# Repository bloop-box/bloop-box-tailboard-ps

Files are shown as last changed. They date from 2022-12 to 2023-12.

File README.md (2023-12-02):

# Bloop Box Tailboard with Power Supply

## THIS IS NO LONGER MAINTAINED AND THEREFORE ARCHIVED! 



Tailboard 3D Render

[Documentation](https://bloop-box.github.io/bloop-box-tailboard)

The board is designed using KiCAD 6 with production and assembly by JLCPCB in mind. All parts are selected to be
available from JLCPCB. At the time of writing as many parts as possible are used from their basic library.

- two power inputs
  - 5.5x2.1mm barrel-jack
  - USB-C
- Can handle 5V to 28V inputs
- Can deliver 5V with up to 3A to the mainboard (assuming it gets enough power)
- Additional circuitry to prevent damage in case two power supplies are connected
- Two buttons connected to the Raspberry Pi, per default used for volume control
- Three LEDs 
  - One to show status of power supply
  - Two can be remote-controlled by Raspberry Pi through the Mainboard

If you just need the 5V USB-C input and don't want the active circuitry you can use the [Tailboard Light](https://github.com/bloop-box/bloop-box-tailboard-light).

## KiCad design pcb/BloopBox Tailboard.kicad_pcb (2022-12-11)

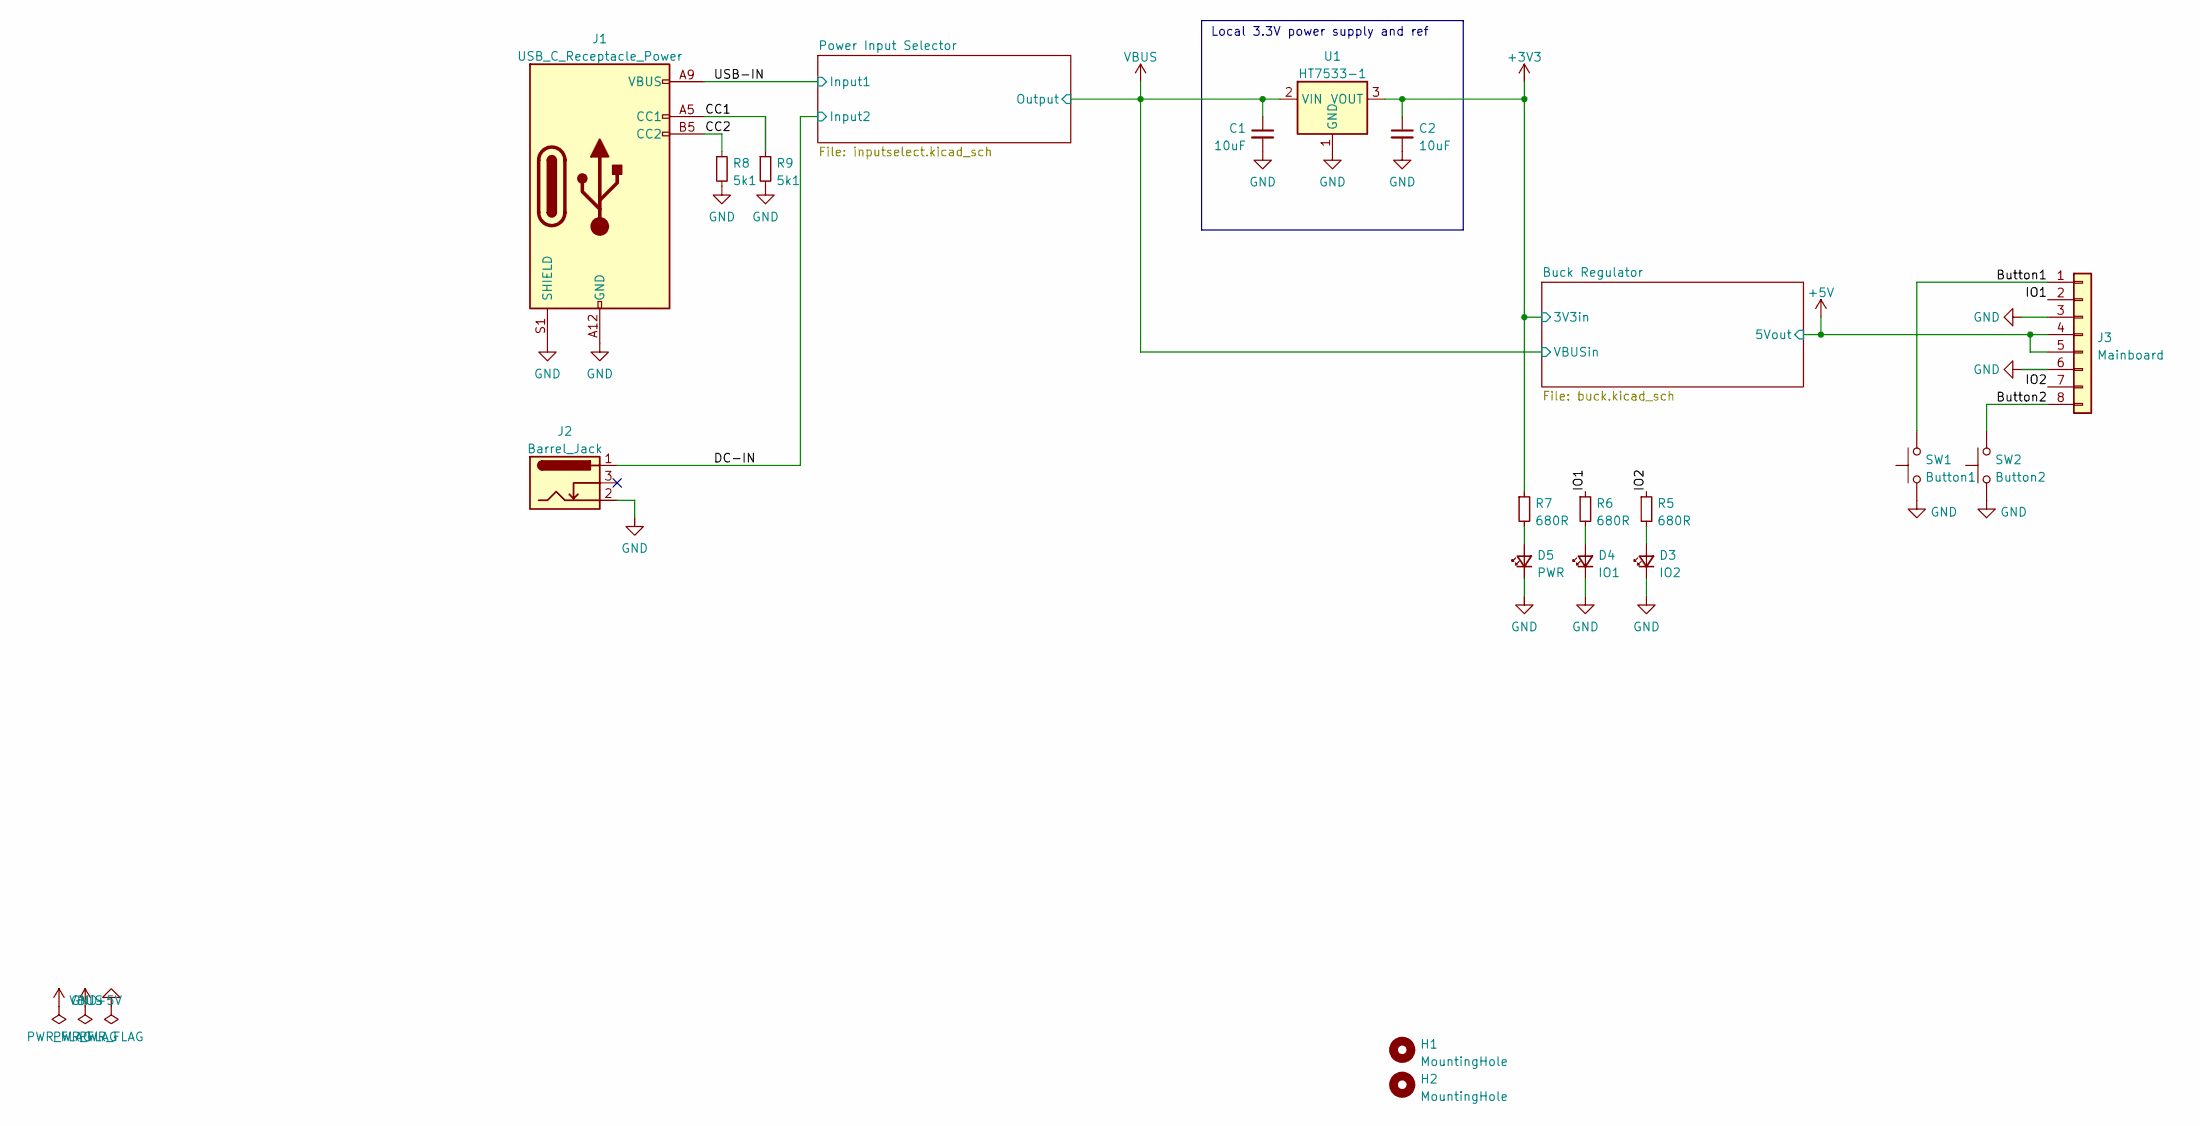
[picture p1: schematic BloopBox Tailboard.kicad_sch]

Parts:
C1: 10uF; C_0805_2012Metric; LCSC C440198
C2: 10uF; C_0402_1005Metric; LCSC C15525
D3: IO2; LED_0603_1608Metric; LCSC C72038
D4: IO1; LED_0603_1608Metric; LCSC C72038
D5: PWR; LED_0603_1608Metric; LCSC C72038
H1, H2: MountingHole; MountingHole_3.2mm_M3_Pad
J1: USB_C_Receptacle_Power; GCT_USB4125-GF-A_REVA2; LCSC C283540
J2: Barrel_Jack; BarrelJack_Horizontal
J3: Mainboard; JST_PH_S8B-PH-K_1x08_P2.00mm_Horizontal; LCSC C14531
R5, R6, R7: 680R; R_0402_1005Metric; LCSC C25130
R8, R9: 5k1; R_0402_1005Metric; LCSC C25905
SW1: Button1; SW_Tactile_SPST_Angled_PTS645Vx83-2LFS; LCSC C338650
SW2: Button2; SW_Tactile_SPST_Angled_PTS645Vx83-2LFS; LCSC C338650
U1: HT7533-1; SOT-89-3; LCSC C14289

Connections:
+3V3: C2.1, R7.1, U1.3 (VOUT); also elsewhere on the board
+5V: J3.4, J3.5; also elsewhere on the board
/Button1: J3.1, SW1.2
/Button2: J3.8, SW2.2
/CC1: J1.A5 (CC1), R9.1
/CC2: J1.B5 (CC2), R8.1
/DC-IN: J2.1; also elsewhere on the board
/IO1: J3.2, R6.1
/IO2: J3.7, R5.1
/USB-IN: J1.A9 (VBUS), J1.B9 (VBUS); also elsewhere on the board
GND: C1.2, C2.2, D3.1 (K), D4.1 (K), D5.1 (K), J1.A12 (GND), J1.B12 (GND), J1.S1 (SHIELD), J2.2, J3.3, J3.6, R8.2, R9.2, SW1.1, SW2.1, U1.1 (GND); also elsewhere on the board
unnamed: D3.2 (A), R5.2
unnamed: D4.2 (A), R6.2
unnamed: D5.2 (A), R7.2
VBUS: C1.1, U1.2 (VIN); also elsewhere on the board

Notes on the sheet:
Local 3.3V power supply and ref

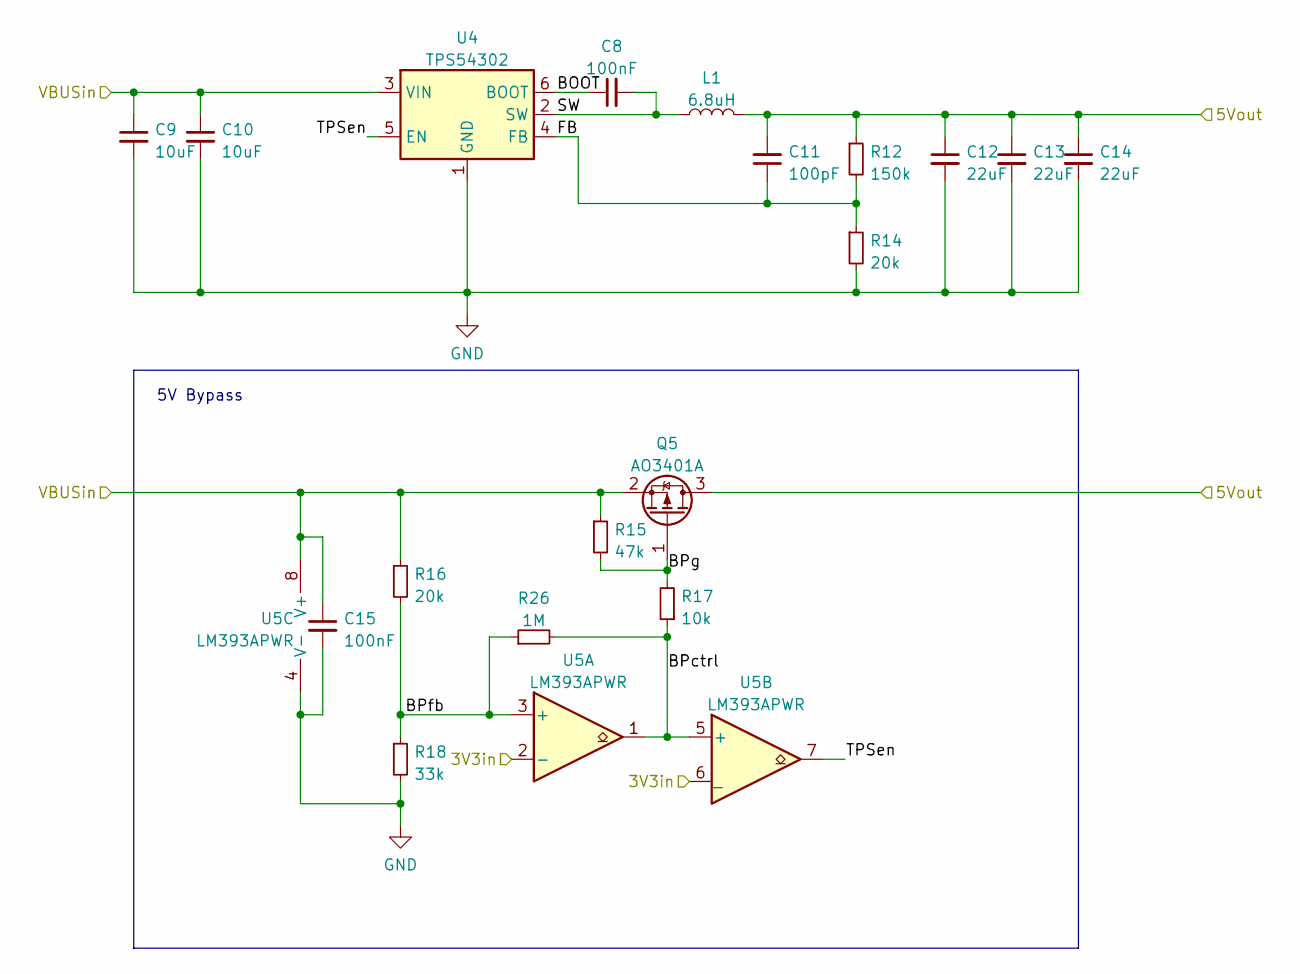
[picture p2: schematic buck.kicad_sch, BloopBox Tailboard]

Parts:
C8: 100nF; C_0402_1005Metric; LCSC C1525
C9, C10: 10uF; C_1206_3216Metric; LCSC C13585
C11: 100pF; C_0402_1005Metric; LCSC C1546
C12, C13, C14: 22uF; C_1206_3216Metric; LCSC C5672
C15: 100nF; C_0402_1005Metric; LCSC C307331
L1: 6.8uH; L_Bourns_SRP7028A_7.3x6.6mm; LCSC C400395
Q5: AO3401A; SOT-23; LCSC C15127
R12: 150k; R_0402_1005Metric; LCSC C25755
R14, R16: 20k; R_0402_1005Metric; LCSC C25765
R15: 47k; R_0402_1005Metric; LCSC C25792
R17: 10k; R_0402_1005Metric; LCSC C25744
R18: 33k; R_0402_1005Metric; LCSC C25779
R26: 1M; R_0402_1005Metric; LCSC C26083
U4: TPS54302; SOT-23-6; LCSC C311983
U5: LM393APWR; TSSOP-8_4.4x3mm_P0.65mm; LCSC C527473

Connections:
+3V3: U5.2 (-), U5.6 (_); also elsewhere on the board
+5V: C11.2, C12.1, C13.1, C14.1, L1.2, Q5.3 (D), R12.1; also elsewhere on the board
/Buck Regulator/BOOT: C8.1, U4.6 (BOOT)
/Buck Regulator/BPctrl: R17.1, R26.2, U5.1, U5.5 (+)
/Buck Regulator/BPfb: R16.2, R18.1, R26.1, U5.3 (+)
/Buck Regulator/BPg: Q5.1 (G), R15.2, R17.2
/Buck Regulator/FB: C11.1, R12.2, R14.1, U4.4 (FB)
/Buck Regulator/SW: C8.2, L1.1, U4.2 (SW)
/Buck Regulator/TPSen: U4.5 (EN), U5.7
GND: C9.2, C10.2, C12.2, C13.2, C14.2, C15.2, R14.2, R18.2, U4.1 (GND), U5.4 (V-); also elsewhere on the board
VBUS: C9.1, C10.1, C15.1, Q5.2 (S), R15.1, R16.1, U4.3 (VIN), U5.8 (V+); also elsewhere on the board

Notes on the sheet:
5V Bypass

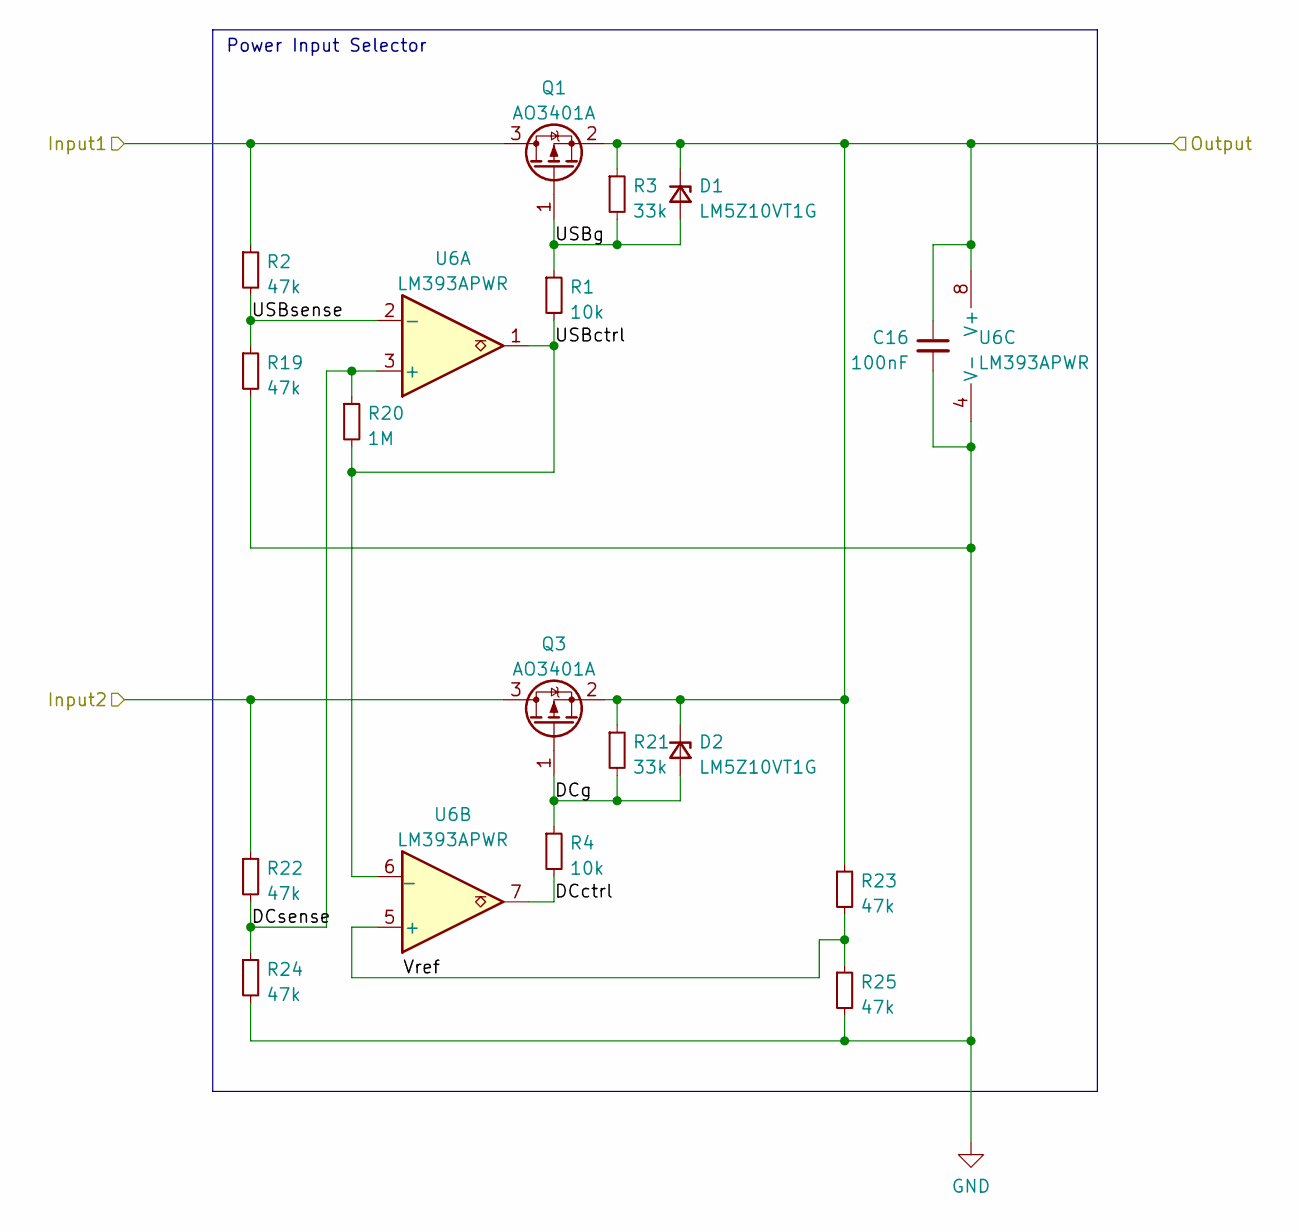
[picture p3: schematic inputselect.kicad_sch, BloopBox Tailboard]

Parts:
C16: 100nF; C_0402_1005Metric; LCSC C307331
D1, D2: LM5Z10VT1G; D_SOD-523; LCSC C525398
Q1, Q3: AO3401A; SOT-23; LCSC C15127
R1, R4: 10k; R_0402_1005Metric; LCSC C25744
R2, R19, R22, R23, R24, R25: 47k; R_0402_1005Metric; LCSC C25792
R3, R21: 33k; R_0402_1005Metric; LCSC C25779
R20: 1M; R_0402_1005Metric; LCSC C26083
U6: LM393APWR; TSSOP-8_4.4x3mm_P0.65mm; LCSC C527473

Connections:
/DC-IN: Q3.3 (D), R22.1; also elsewhere on the board
/Power Input Selector/DCctrl: R4.2, U6.7
/Power Input Selector/DCg: D2.2 (A), Q3.1 (G), R4.1, R21.2
/Power Input Selector/DCsense: R20.1, R22.2, R24.1, U6.3 (+)
/Power Input Selector/USBctrl: R1.2, R20.2, U6.1, U6.6 (_)
/Power Input Selector/USBg: D1.2 (A), Q1.1 (G), R1.1, R3.2
/Power Input Selector/USBsense: R2.2, R19.1, U6.2 (-)
/Power Input Selector/Vref: R23.2, R25.1, U6.5 (+)
/USB-IN: Q1.3 (D), R2.1; also elsewhere on the board
GND: C16.2, R19.2, R24.2, R25.2, U6.4 (V-); also elsewhere on the board
VBUS: C16.1, D1.1 (K), D2.1 (K), Q1.2 (S), Q3.2 (S), R3.1, R21.1, R23.1, U6.8 (V+); also elsewhere on the board

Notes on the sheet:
Power Input Selector

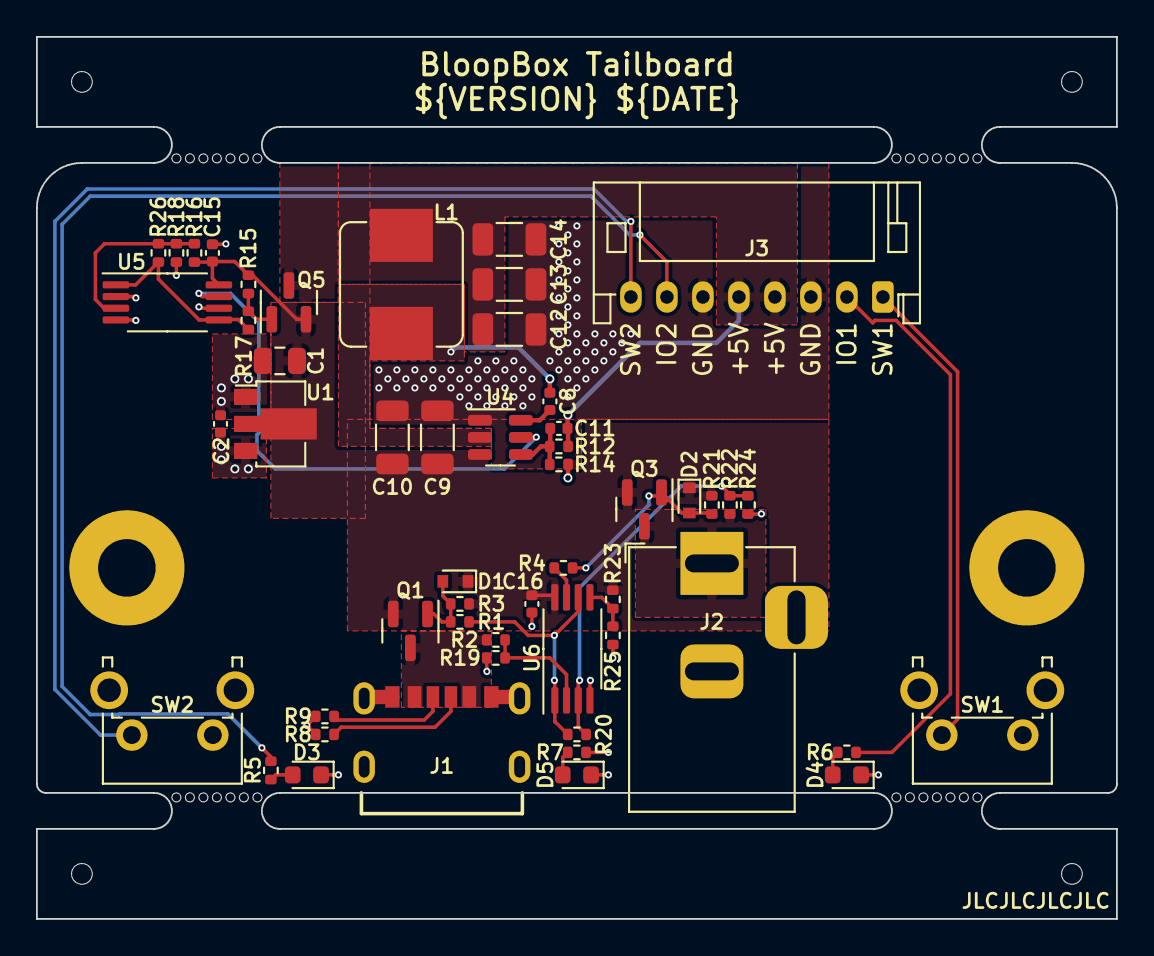
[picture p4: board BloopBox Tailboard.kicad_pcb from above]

Board: 4 copper layers, 60.0 x 49.0 mm, 58 parts (0 on the bottom side), 29 nets.

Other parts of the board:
mouse-bite-2mm-slot, mouse-bite-2mm-slot#2, mouse-bite-2mm-slot#3, mouse-bite-2mm-slot#4: VAL**; mouse-bite-2x5mm-slot-onesided

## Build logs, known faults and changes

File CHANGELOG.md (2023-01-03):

# Changelog

## 1.0.0 (2022-12-12)

### ⚠ BREAKING CHANGES

* remove Power Delivery circuitry

### Features

* add and use versioning variables ([50b8ece](https://github.com/bloop-box/bloop-box-tailboard/commit/50b8eceeff82ba3242f2a5cd8d48997ad7749272))
* split tailboard into standalone repository ([192a561](https://github.com/bloop-box/bloop-box-tailboard/commit/192a5616ad0d687bc7e60cdefae15836de21bafe))

### Bug Fixes

* add missing LCSC part numbers ([aee9bbc](https://github.com/bloop-box/bloop-box-tailboard/commit/aee9bbc0874995dc930b6d6546f51aa283abd91d))
* remove Power Delivery circuitry ([44b3360](https://github.com/bloop-box/bloop-box-tailboard/commit/44b3360d34a09fa9a17619a7a237e2e1e54ea48a))

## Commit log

2022-12-02 ci: add remaining boards to kibot
2022-12-02 chore: remove .kicad_prl files from git
2022-12-03 chore: add KiCAD autosave files to .gitignore
2022-12-03 style(Tailboard): rev number +.1
    Forgot to change this...
    [BloopBox Tailboard.kicad_pcb, BloopBox Tailboard.kicad_sch, buck.kicad_sch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]
2022-12-04 feat: split tailboard into standalone repository
    [BloopBox Tailboard.kicad_pcb, BloopBox Tailboard.kicad_sch, buck.kicad_sch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]
2022-12-04 feat: add and use versioning variables
    [BloopBox Tailboard.kicad_pcb, BloopBox Tailboard.kicad_sch, buck.kicad_sch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]
2022-12-09 fix!: remove Power Delivery circuitry
    PD circuit was removed because it didn't work as planned in the current version and fixing it would make the board too expensive. The USB-C port is now hardwired to request 5V/3A.
    [BloopBox Tailboard.kicad_pcb, BloopBox Tailboard.kicad_sch, powerdelivery.kicad_sch]
2022-12-09 docs: update README
    Remove Power Deliver and change description of LED functionality
2022-12-11 fix: add missing LCSC part numbers
    [BloopBox Tailboard.kicad_pcb, BloopBox Tailboard.kicad_sch, buck.kicad_sch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]
